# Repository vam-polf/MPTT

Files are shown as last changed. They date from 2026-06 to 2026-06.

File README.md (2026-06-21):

# MPTT — Mini Push To Talk

> LoRa 对讲机 v0.1 | STM32WLE5 + WM8960 | 2层 FR-4 35×55mm

基于 E77-400M22S (STM32WLE5) 和 WM8960 音频 Codec 的 LoRa 手持对讲机。单节锂电池供电，USB-C 充电，SMA 外接天线。

## 目录结构

```
mptt/
├── README.md                 本文件
├── docs/                     设计文档 (见 docs/README.md)
├── hardware/                 硬件设计 (原理图、BOM、PCB、EasyEDA 工程)
├── reference/datasheets/     芯片数据手册
└── firmware/                 固件
    ├── build.bat             构建主固件 (Windows)
    ├── Makefile              构建 / 烧录快捷入口
    ├── link.ld               链接脚本
    ├── startup.c             启动代码
    ├── include/              头文件
    │   ├── stm32wle5xx.h     MCU 寄存器定义
    │   └── audio_wm8960.h    音频驱动 API
    ├── src/                  源代码
    │   ├── main.c            应用层 (PTT 状态机 + DSP 后处理)
    │   └── audio_wm8960.c    音频底层 (MCLK/I2C/I2S/WM8960, 已冻结)
    ├── tools/                调试 / 验证脚本 (pyocd)
    │   ├── selftest.py       自动验证 (模拟 PTT, 无需人工)
    │   ├── readproc.py       读取处理后缓冲 → WAV
    │   ├── readdiag.py       读取 DIAG 诊断区
    │   └── ...
    └── build/                构建产物 (gitignore)
        ├── fw.elf
        └── fw.bin
```

## 固件快速开始

```bat
cd firmware
build.bat
pyocd flash -t stm32wle5cbux build\fw.bin
python tools\selftest.py
```

音频底层配置与调试知识库见 `D:\kb\wm8960\mptt-从零调试实战手册.md`。

## 核心器件

| 位号 | 型号 | 功能 |
|---|---|---|
| U1 | E77-400M22S | STM32WLE5 LoRa 模组, 400-470MHz |
| U2 | WM8960CGEFL/RV | 音频 Codec + 1W D类功放 |
| U3 | ME6211C33M5G-N | 3.3V 500mA LDO |
| U4 | TP4056-42-ESOP8 | 锂电池充电管理 |
| U5 | DW01A + U6 8205A | 电池保护 + MOSFET 开关 |

## 设计工具

- **EDA**: 立创EDA专业版
- **PCB**: JLCPCB 2层 FR-4, 35×55mm

## 许可证

MIT License

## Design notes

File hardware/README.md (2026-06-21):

# 硬件文档索引

| 文件 | 内容 |
|---|---|
| [SCHEMATIC.md](SCHEMATIC.md) | 原理图模块说明、关键引脚 |
| [NETLIST.md](NETLIST.md) | 40 网络连接表（含 I2S 半双工） |
| [BOM.md](BOM.md) | 物料清单 53 项 |
| [PCB.md](PCB.md) | PCB 布局与生产 |
| `lora_waikie_2026-06-05.epro2` | EasyEDA Pro 工程源文件 |
| `mptt_schematic_v0.1.pdf` | 原理图 PDF 导出 |

引脚与固件对应关系以 **SCHEMATIC.md + NETLIST.md** 为准（2026-06-21 已与 bringup 固件交叉核对）。

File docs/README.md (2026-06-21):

# 文档索引

| 文档 | 内容 |
|---|---|
| [DESIGN_v0.1.md](DESIGN_v0.1.md) | v0.1 **硬件**系统设计（架构、电源、WM8960、BOM、PCB 指南） |

固件架构与音频调试（WM8960 寄存器、I2S 时钟、PTT 录放）见知识库：

- `D:\kb\wm8960\mptt-从零调试实战手册.md`（最终实测配置，权威）
- 代码：`firmware/src/main.c`（应用）、`firmware/src/audio_wm8960.c`（音频驱动）

硬件接线速查见 `hardware/SCHEMATIC.md`、`hardware/NETLIST.md`。

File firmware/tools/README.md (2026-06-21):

# pyocd 调试 / 验证工具

在 `firmware/` 目录下运行:

```bat
python tools\selftest.py      # 自动模拟 PTT, 客观验证通路
python tools\readdiag.py        # 读 DIAG 诊断区 (不复位)
python tools\readproc.py        # 导出处理后音频 → tools\output\proc.wav
python tools\noiseanalyze.py    # 频谱分析
python tools\read_wm.py         # 读 WM8960 shadow (I2C 探测)
python tools\probe.py           # GPIO / 外设快照
```

生成的 WAV 文件写入 `tools/output/` (已 gitignore)。

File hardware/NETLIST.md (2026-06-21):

# 网络连接表 v0.1

> 40 个网络 | 作者: vam-polf | 2026-06-07

## 电源域

| 网络 | 电压 | 来源 | 用途 |
|---|---|---|---|
| USB_5V | 5V | USB-C (J1) | 充电输入 |
| BAT+ | 3.7-4.2V | 锂电池正极 | 电池供电 |
| DWBAT+ | 3.7-4.2V | DW01A 输出 | 保护后的电池电压 |
| BAT- | GND | 电池负极 | 电池回路 |
| +3.3V | 3.3V | ME6211 LDO 输出 | 主供电 |
| +3.3V_E77 | 3.3V | 经0Ω跳线 | E77 模块专用供电 |
| +3.3V_DVDD | 3.3V | WM8960 数字供电 | 音频数字部分 |
| +3.3V_BVDD | 3.3V | WM8960 缓冲供电 | 音频缓冲 |
| +3.3V_AVDD | 3.3V | WM8960 模拟供电 | 音频模拟部分 |
| +1.65V | 1.65V | WM8960 内部 VREF | 中点参考电压 |
| VBAT_SPK | 3.7-4.2V | 电池直供 SPKVDD | 扬声器功放供电 |

## 电源管理

| 网络 | 功能 |
|---|---|
| PROG | TP4056 充电电流设置 (R17/R18分压 ≈5.1kΩ→~200mA) |
| CHRG | TP4056 充电状态指示 (LED U8) |
| STDBY | TP4056 充满指示 (LED U9) |
| OC | DW01A 过充检测 |
| OD | DW01A 过放检测 |
| VM | DW01A 过流检测 |

## USB-C

| 网络 | 功能 |
|---|---|
| CC1 | USB-C CC1 配置通道 (5.1kΩ下拉) |
| CC2 | USB-C CC2 配置通道 (5.1kΩ下拉) |

## 射频

| 网络 | 功能 |
|---|---|
| ANT | SMA 天线连接 (J2), 50Ω 匹配 |

## 数字音频 (I2S)

| 网络 | MCU 引脚 | 方向 | 功能 |
|---|---|---|---|
| I2S_MCLK | PA3 (TIM2_CH4) | E77→WM8960 pin11 | 主时钟 2.286MHz (PWM, 非 I2S2_MCK) |
| I2S_BCLK | PA8 (I2S2_CK) | 录: WM8960→E77 / 放: E77→WM8960 pin12 | 位时钟 |
| I2S_LRCLK | PA9 (I2S2_WS) | 同上 pin13 (DACLRC) | 帧时钟 |
| I2S_SD | PA10 (I2S2_SD) | **半双工共线** pin14+16 | 录音 ADCDAT→MCU / 播放 MCU→DACDAT |
| ADCLRC | — (PCB 浮空) | — | WM8960 pin15 未接 MCU；固件 R9 ALRCGPIO=1 |

> 录音时 WM8960 当 I2S 主、STM32 当从；播放时相反。详见 `firmware/src/audio_wm8960.c`。

## 控制总线 (I2C)

| 网络 | 功能 |
|---|---|
| I2C_SCL | WM8960 配置时钟 |
| I2C_SDA | WM8960 配置数据 |

## 模拟音频

| 网络 | 功能 |
|---|---|
| MIC+ | 驻极体麦克风 正极输入 |
| MICBIAS | WM8960 麦克风偏置电压 |
| LINPUT1 | 线路输入 1 / 麦克风输入 |
| SPK_LP | 扬声器 左声道 正极 |
| SPK_LN | 扬声器 左声道 负极 |

## 控制/调试

| 网络 | 功能 |
|---|---|
| NRST | 系统复位 |
| SWDIO | SWD 调试数据 |
| SWCLK | SWD 调试时钟 |
| PTT | 对讲按键 (Push-To-Talk) |
| BAT_ADC | 电池电压 ADC 采样 |

## 内部网络

| 网络 | 说明 |
|---|---|
| $1N287 | 内部网络 (自动生成) |
| $1N290 | 内部网络 (自动生成) |
| GND | 公共地 |

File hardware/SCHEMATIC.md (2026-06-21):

# 原理图设计说明 v0.1

> EasyEDA Pro | 单页原理图 P1 | 53 个元件 | 作者: vam-polf | 2026-06-07

## 功能模块划分

### 1. 核心控制 — E77-400M22S (U1)

STM32WLE5 内置 LoRa 射频的单片机模组。负责:
- LoRa 无线收发 (400MHz)
- I2S 音频数据流控制
- I2C 配置 WM8960
- GPIO 控制 PTT/充电状态
- ADC 电池电压采样

关键引脚连接:
- PA3(TIM2_CH4 MCLK)/PA8(I2S2_CK)/PA9(I2S2_WS)/PA10(I2S2_SD) → I2S 到 WM8960
- PB6/PB7 → I2C 到 WM8960
- PB8 → PTT 按键（上拉，按下=低；固件见 `firmware/src/main.c`）
- PA0 → BAT_ADC
- PA13/PA14 → SWD (J4)

### 2. 音频编解码 — WM8960 (U2)

立体声音频 Codec + 1W D类功放。

模拟部分:
- MIC+/LINPUT1 → 麦克风输入
- SPK_LP/SPK_LN → 扬声器输出 (BTL 桥接)
- MICBIAS → 驻极体偏置

数字部分:
- I2S: MCLK(PA3) / BCLK(PA8) / LRCLK(PA9) / SD(PA10 半双工)
- ADCLRC (WM8960 pin15): **PCB 浮空**，固件设 ALRCGPIO=1
- I2C 配置接口 (PB6/PB7 → SCL/SDA)

电源分组:
- +3.3V_DVDD: 数字核心
- +3.3V_BVDD: 缓冲器
- +3.3V_AVDD: 模拟电路
- VBAT_SPK: 功放级 (直连电池)

### 3. 电源管理

```
USB-C 5V → TP4056 → DW01A → 8205A → BAT+
                         ↓
                    ME6211 → +3.3V → 各路供电
```

- **TP4056 (U4)**: 恒流/恒压充电, 200mA 充电电流, LED 状态指示
- **DW01A (U5)**: 过充(4.25V)/过放(2.5V)/过流保护
- **8205A (U6)**: 双 MOSFET 开关, 切断电池回路
- **ME6211 (U3)**: 3.3V 500mA LDO, 输入6V, 低压差

### 4. USB-C 接口 (J1)

- VBUS → USB_5V (充电输入)
- D+/D- → E77 USB (预留, 当前未连)
- CC1/CC2 → 各接 5.1kΩ 下拉 (R17/R18)

### 5. 天线接口 (J2)

SMA 母座, 50Ω 特性阻抗。PCB 走线需控制阻抗。

### 6. 外设接口

| 连接器 | 用途 |
|---|---|
| J3 (1.25mm 2P) | 锂电池连接 |
| J4 (2.54mm 2×3P) | SWD 调试 (SWDIO/SWCLK/NRST/GND) |
| J5 (ZH 1.5mm 2P) | 扬声器 8Ω/1W |
| J6 (ZH 1.5mm 2P) | 驻极体麦克风 |

## 设计规则

- 原理图坐标单位: 0.01inch (10 mil)
- 元件总数: 53
- 网络总数: 40
- DRC 状态: 通过

## 去耦电容布局

每个 IC 电源引脚就近放置 100nF + 10μF/22μF 去耦电容:
- E77: C9/C10/C11/C12/C13/C14/C15/C16/C17 + 电源隔离 (R7/R8/R9/R10/R11 0Ω 跳线)
- WM8960: C1/C2/C3/C4/C5 + 各电源域独立去耦
- ME6211: 输入 C18 (1μF), 输出大电容组
- TP4056: 输入/输出电容

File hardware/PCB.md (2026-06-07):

# PCB 设计说明 v0.1

> 2层 FR-4 | 35×55mm | 作者: vam-polf | 2026-06-07

## 物理参数

| 参数 | 值 |
|---|-----|
| 层数 | 2 层 (Top/Bottom) |
| 板厚 | 1.6 mm |
| 铜厚 | 1 oz |
| 基材 | FR-4 |
| 最小线宽 | 6 mil |
| 最小间距 | 6 mil |
| 最小过孔 | 0.3mm 钻孔 / 0.6mm 外径 |
| 阻焊颜色 | 绿色 |
| 字符颜色 | 白色 |
| 焊盘喷镀 | 有铅喷锡 |
| 过孔处理 | 过孔盖油 |

## 布局策略

### 区域划分

```
┌─────────────────────────────────────┐
│  ANT (J2)    E77 (U1)     TP4056    │
│   SMA         LoRa         U4       │
│                                      │
│                       DW01A + 8205A │
│  WM8960 (U2)        U5    +  U6     │
│    Audio                            │
│                                      │
│  J1 USB-C   ME6211    SWD   Batt    │
│             (U3)      (J4)  (J3)    │
└─────────────────────────────────────┘
```

### 布局原则

1. **RF 优先**: 天线区域远离数字噪声源, SMA 座靠近 E77, 50Ω 走线尽量短
2. **电源分区**: 充电/保护电路远离音频模拟区域
3. **去耦就近**: 每个 IC 电源引脚 2mm 内放置去耦电容
4. **GND 完整性**: 底面大面积 GND 铜皮, 顶面保留 GND 回路

### 关键走线

| 走线 | 宽度 | 层 | 说明 |
|---|---|-----|---|
| ANT (RF) | 计算阻抗 | Top | 50Ω 微带线 |
| BAT+ / USB_5V | 30-40 mil | Top | 大电流电源 |
| VBAT_SPK | 30 mil | Top | 功放供电 |
| 信号线 | 12 mil | Top/Bottom | 通用信号 |
| GND | 铺铜 | Bottom | 完整地平面 |

## 元件面分配

全部元件置于 **Top Layer**:
- 52 个 SMD 元件 (Top)
- 1 个直插元件 J4 (2.54mm 2×3P SWD)
- 0 个元件在 Bottom

## 生产文件

通过 EasyEDA Pro → 文件 → 导出 → 嘉立创PCB下单 直接生成 Gerber。
或在 EDA 中导出:
- Gerber (RS-274X)
- NC Drill
- BOM (CSV)
- CPL 坐标文件 (CSV)

## SMT 贴片

- 只贴顶层
- JLCPCB 标准型 SMT
- E77 和 WM8960 需邮寄物料 (嘉立创无现货)

## 已知限制

- WM8960 已停产，需从淘宝/库存采购
- RF 天线走线未做严格阻抗仿真 (第一版原型)
- 无屏蔽罩，RF 可能干扰音频电路

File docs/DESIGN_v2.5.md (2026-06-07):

# MPTT v2.5 硬件设计文档

> LoRa 对讲机 | E77-400M22S (STM32WLE5) + WM8960 | 2层 FR-4 35×55mm
> 设计日期: 2026-06-07 | EDA: 立创EDA专业版 V3.2.121

---

## 目录

1. [系统概述](#1-系统概述)
2. [架构框图](#2-架构框图)
3. [核心模组: E77-400M22S](#3-核心模组-e77-400m22s)
4. [音频子系统: WM8960](#4-音频子系统-wm8960)
5. [电源管理](#5-电源管理)
6. [接口与外设](#6-接口与外设)
7. [电源树与去耦策略](#7-电源树与去耦策略)
8. [物料清单 (BOM)](#8-物料清单-bom)
9. [PCB 设计指南](#9-pcb-设计指南)
10. [设计决策与取舍](#10-设计决策与取舍)

---

## 1. 系统概述

MPTT v2.5 是一款基于 STM32WLE5 的 LoRa 手持对讲机。单节锂电池供电，USB-C 充电，SMA 外接天线。

### 1.1 核心能力

| 功能 | 实现 |
|---|---|
| 无线通信 | E77-400M22S LoRa 扩频模块, 400-470MHz |
| 音频采集 | 驻极体麦克风 → WM8960 ADC → I2S → MCU |
| 音频播放 | MCU → I2S → WM8960 DAC → 1W D类功放 → 扬声器 |
| 电源 | 单节锂电池, TP4056 充电, DW01A 保护, ME6211 LDO |
| 调试 | SWD 2×3P 接口 |
| 充电 | USB-C (5V/200mA) |

### 1.2 设计选型理由

选用**模组方案**（E77-400M22S）而非裸芯片，原因：
- 避免 RF 阻抗匹配和天线设计的复杂性
- 模组已过 FCC/CE 认证
- 内置 STM32WLE5 + RF 前端，缩小 PCB 面积
- 简单、稳定、可靠

选用**WM8960 模拟 Codec** 而非数字 MEMS 麦克风方案，原因：
- 驻极体麦克风成本极低（~1元），数字 MEMS 需 5-10 元
- WM8960 内置 1W D 类功放，无需额外功放 IC
- 立体声能力为未来扩展预留

---

## 2. 架构框图

```
                        ┌──────────────────────────────────────┐
   SMA Antenna ────────►│                                      │
                        │         E77-400M22S (U1)              │
                        │     STM32WLE5 + SX1262 RF Frontend    │
                        │                                      │
                        │  ┌─────────────────────────────────┐ │
   PTT Button (SW1) ───┼──► PB0 (GPIO)                       │ │
                        │  │                                  │ │
   Battery ADC ────────┼──► PA0 (ADC)                        │ │
                        │  │                                  │ │
   SWD (J4) ───────────┼──► PA13(SWDIO) / PA14(SWCLK)        │ │
                        │  │                                  │ │
                        │  │   I2S ┌──────────────────────┐   │ │
                        │  │  ───►│    WM8960 (U2)        │   │ │
                        │  │  ◄───│  Audio Codec + Amp    │   │ │
                        │  │      │                       │   │ │
                        │  │  I2C │  MIC+ ◄── J6 (Mic)   │   │ │
                        │  │  ───►│  SPK  ──► J5 (Spkr)  │   │ │
                        │  │      └──────────────────────┘   │ │
                        │  └─────────────────────────────────┘ │
                        │                                      │
                        │   Power ┌────────────────────────┐   │
   USB-C (J1) ─────────┼────────►│ TP4056 → BAT → DW01A   │   │
                        │         │   ↓          ↓         │   │
   Battery (J3) ───────┼────────►│ ME6211 → +3.3V         │   │
                        │         └────────────────────────┘   │
                        └──────────────────────────────────────┘
```

---

## 3. 核心模组: E77-400M22S

### 3.1 模组规格

| 参数 | 值 |
|---|-----|
| 型号 | E77-400M22S |
| MCU | STM32WLE5CBU6 (ARM Cortex-M4 48MHz) |
| RF 芯片 | SX1262 |
| 频段 | 400-470 MHz |
| 发射功率 | 最大 +22 dBm |
| 接收灵敏度 | -138 dBm @ SF12 BW=125kHz |
| Flash/RAM | 128KB / 48KB |
| 供电 | 1.8-3.6V |
| 尺寸 | 14×20 mm (邮票孔封装) |
| LCSC | C2777170 |

### 3.2 引脚分配

#### I2S 音频接口

| E77 引脚 | STM32 功能 | 连接目标 | 说明 |
|---|---|---|---|
| 8 | PA4 (I2S1_WS) | WM8960 ADCLRC | ADC 字时钟 |
| 9 | PA5 (I2S1_CK) | WM8960 I2S_BCLK | I2S 位时钟 |
| 10 | PA6 (I2S1_SD) | WM8960 I2S_SD | I2S 数据输出 (MCU→Codec) |
| 11 | PA7 (I2S1_MCK) | WM8960 I2S_MCLK | 主时钟 |

#### I2C 控制接口

| E77 引脚 | 功能 | 连接目标 |
|---|---|---|
| 14 | PB6 (I2C1_SCL) | WM8960 SCL |
| 15 | PB7 (I2C1_SDA) | WM8960 SDA |

#### 控制与状态

| E77 引脚 | 功能 | 连接目标 | 说明 |
|---|---|---|---|
| 1 | NRST | J4 (SWD) + R19上拉 | 系统复位, 100kΩ 上拉到 +3.3V |
| 18 | PB0 | SW1 (PTT) + R12下拉 | 对讲按键, 4.7kΩ 下拉 |
| 16 | PA0 (ADC) | BAT_ADC (R20分压) | 电池电压检测, 100kΩ分压 |

#### SWD 调试

| E77 引脚 | 功能 | J4 引脚 |
|---|---|---|
| 2 | PA13 (SWDIO) | J4-3 |
| 3 | PA14 (SWCLK) | J4-4 |
| 1 | NRST | J4-5 |

### 3.3 E77 电源与去耦

- VCC 由 `+3.3V_E77` 供电（通过 0Ω 跳线 R7/R8/R9/R10/R11 与主 3.3V 隔离）
- 多组去耦电容: C9(100nF), C10(100nF), C11(10μF), C12(100nF), C13(100nF), C14(22μF), C15(100nF), C16(10μF), C17(10μF)
- 0Ω 跳线允许独立测量 E77 功耗

---

## 4. 音频子系统: WM8960

### 4.1 Codec 规格

| 参数 | 值 |
|---|-----|
| 型号 | WM8960CGEFL/RV |
| 封装 | QFN-32 (5×5mm) |
| DAC SNR | 98dB |
| ADC SNR | 94dB |
| 功放输出 | 1W @ 8Ω (D类, BTL) |
| 耳机输出 | 40mW @ 16Ω |
| 麦克风 | 差分/单端, 内置 PGA + ALC |
| 接口 | I2S (标准/左对齐/DSP), I2C 控制 |
| 状态 | ⚠️ 已停产, 需淘宝/库存采购 |

### 4.2 信号链

```
TX路径 (发送):
  Electret Mic → MIC+/LINPUT1 → WM8960 PGA → ADC → I2S_SD → E77 → LoRa TX

RX路径 (接收):
  LoRa RX → E77 → I2S_SD → WM8960 DAC → D类功放 → SPK_LP/SPK_LN → Speaker (J5)
```

### 4.3 WM8960 引脚连接

#### I2S 数字音频

| WM8960 引脚 | 信号 | 连接 |
|---|---|---|
| 13 | ADCLRC | E77 PA4 (I2S1_WS) |
| 14 | DACLRC | E77 PA7 (I2S1_MCK) — 复用为 LRC |
| 15 | BCLK | E77 PA5 (I2S1_CK) |
| 16 | ADCDAT | E77 PA6 (I2S1_SD) |
| 17 | DACDAT | E77 PA7 — 双向数据 |

#### I2C 控制

| WM8960 引脚 | 连接 |
|---|---|
| 19 (SCLK) | E77 PB6 (I2C1_SCL) |
| 20 (SDIN) | E77 PB7 (I2C1_SDA) |

I2C 地址: 0x1A (7-bit, CSB=GND)

#### 模拟音频

| WM8960 引脚 | 功能 | 外部连接 |
|---|---|---|
| 8 (LINPUT1) | 麦克风输入 | 驻极体 MIC+ (J6), 隔直电容 |
| 9 (MICBIAS) | 麦克风偏置 | 通过电阻供电给驻极体 |
| 25 (SPK_LP) | 扬声器 正 | J5-1 (ZH1.5 2P) |
| 26 (SPK_LN) | 扬声器 负 | J5-2 |

SPK_LP/SPK_LN 为 BTL 桥接输出，无需隔直电容。

#### 电源分组

WM8960 有多组独立电源域，需分别去耦：

| 电源引脚 | 网络 | 去耦 |
|---|---|---|
| 1, 2, 31 (AVDD) | +3.3V_AVDD | C1(22μF) + C2(100nF) + C3(100nF) |
| 10, 18 (DVDD) | +3.3V_DVDD | C5(10μF) + C6(100nF) |
| 22 (SPKVDD1) | VBAT_SPK | 电池直供, C7(22μF) + C8(100nF) |
| 28 (SPKVDD2) | VBAT_SPK | 同上 |
| 12 (DBVDD) | +3.3V_BVDD | 缓冲供电 |

**设计要点**: SPKVDD 直接接电池电压 (3.7-4.2V)，不经过 3.3V LDO。D 类功放在较高电压下效率更好。

### 4.4 麦克风电路

- 驻极体麦克风 (6027 单指向, -42dB, 6×2.7mm)
- MICBIAS 提供偏置电压 (~2.0V via WM8960 内部)
- 隔直电容 (C4) 耦合到 LINPUT1
- 差分输入可抑制共模噪声

---

## 5. 电源管理

### 5.1 电源架构

```
USB-C 5V (J1)
   │
   ▼
┌──────────┐    ┌──────────┐    ┌──────────┐
│  TP4056  │───►│  DW01A   │───►│  8205A   │──► BAT+ (J3)
│  Charger │    │ Protect  │    │ MOSFET   │
│  U4      │    │  U5      │    │  U6      │
└────┬─────┘    └──────────┘    └──────────┘
     │
     ├── CHRG ──► U8 (Red LED)  充电指示
     └── STDBY ─► U9 (Green LED) 充满指示

BAT+ ──► ME6211 (U3) ──► +3.3V ──┬── +3.3V_E77 (经0Ω跳线)
                                  ├── +3.3V_AVDD
                                  ├── +3.3V_DVDD
                                  └── +3.3V_BVDD

BAT+ ──► VBAT_SPK (WM8960 功放直供)
```

### 5.2 TP4056 充电管理 (U4)

| 参数 | 值 | 设置方式 |
|---|-----|---|
| 充电电流 | ~200mA | R17//R18 → 5.1kΩ → PROG 引脚 |
| 终止电流 | C/10 (~20mA) | 内部固定 |
| 充电电压 | 4.2V ±1% | 内部固定 |
| 输入电压 | 4.5-6V (USB-C 5V) | |
| 温度保护 | 禁用 | TEMP 引脚接 GND |

充电状态指示:
- CHRG (开漏): 充电中 → LED U8 (红) 亮
- STDBY (开漏): 充满 → LED U9 (绿) 亮
- 两个 LED 均通过限流电阻 (R16: U8, R14: U9) 连接到 +3.3V

**充电电流计算**: I_CHG = 1000V / R_PROG
- R17 = 5.1kΩ, R18 = 5.1kΩ 并联 → R_PROG ≈ 2.55kΩ
- I_CHG ≈ 392mA (理论值)
- 实际限流约 200mA (考虑 USB 供电能力)

### 5.3 DW01A 电池保护 (U5) + 8205A MOSFET (U6)

DW01A 监控电池状态，通过 8205A 双 MOSFET 切断充放电回路：

| 保护功能 | 阈值 | 动作 |
|---|---|---|
| 过充保护 | 4.25V ±50mV | OC→高, 切断充电 MOSFET |
| 过放保护 | 2.40V ±100mV | OD→高, 切断放电 MOSFET |
| 放电过流 | 150mV (≈3A) | OD→高 |
| 短路保护 | 1.5V | 立即切断 |

8205A: 双 N 沟道 MOSFET, Vds=20V, Id=6A, Rds(on)=25mΩ

### 5.4 ME6211 LDO (U3)

| 参数 | 值 |
|---|-----|
| 型号 | ME6211C33M5G-N |
| 封装 | SOT-23-5 |
| 输入电压 | 最大 6V |
| 输出电压 | 3.3V 固定 |
| 输出电流 | 最大 500mA |
| 压差 | 100mV @ 200mA |
| LCSC | C82942 |

输入电容 C18 (1μF), 输出电容由各路去耦组成。

### 5.5 功耗估算

| 工作模式 | E77 | WM8960 | 其他 | 总计 |
|---|-----|---|---|---|
| RX 监听 | ~8mA | ~2mA | ~1mA | ~11mA |
| TX (22dBm) | ~120mA | ~10mA | ~1mA | ~131mA |
| 待机 | ~2μA | 0 (掉电) | ~5μA | ~7μA |

500mAh 电池续航: RX ~45小时, TX ~3.5小时

---

## 6. 接口与外设

### 6.1 USB-C (J1)

| 引脚 | 连接 | 说明 |
|---|---|---|
| VBUS | USB_5V | 充电输入 |
| D+/D- | NC | 数据线未使用 (E77 USB 预留) |
| CC1 | 5.1kΩ 下拉 (R17) | 配置为 UFP (受电设备) |
| CC2 | 5.1kΩ 下拉 (R18) | 同上 |
| GND | GND | |

Type-C 母座, 卧贴封装。CC1/CC2 各接 5.1kΩ 到 GND → USB-C 主机识别为需要 5V 供电的设备。

### 6.2 SMA 天线 (J2)

- 型号: SMA-KE-5 (母座, 正脚)
- 50Ω 特性阻抗
- 走线尽量短, 参考地层完整
- 无额外匹配网络 (E77 模组内部已匹配)

### 6.3 SWD 调试接口 (J4)

2×3P, 2.54mm 间距, 直插方针:

| 引脚 | 信号 |
|---|---|
| 1 | +3.3V |
| 2 | SWDIO |
| 3 | GND |
| 4 | SWCLK |
| 5 | GND |
| 6 | NRST |

### 6.4 电池连接器 (J3)

1×2P, 1.25mm PicoBlade 卧贴:
- Pin 1: BAT+ (正极)
- Pin 2: GND (负极)

### 6.5 扬声器 (J5)

ZH 1.5mm 1×2P 立贴:
- Pin 1: SPK_LP (WM8960 输出正)
- Pin 2: SPK_LN (WM8960 输出负)

推荐扬声器: 8Ω/1W, 直径 20mm 腔体

### 6.6 麦克风 (J6)

ZH 1.5mm 1×2P 立贴:
- Pin 1: MIC+ (经隔直电容到 WM8960 LINPUT1)
- Pin 2: GND

推荐麦克风: 6027 单指向驻极体, -42dB

### 6.7 PTT 按键 (SW1)

- 型号: TS-1187A-B-A-B (5.1×5.1×1.5mm 立贴)
- 连接: PB0 → SW1 → GND
- 内部上拉: E77 PB0 内置弱上拉
- 外部下拉: R12 (4.7kΩ) 确保默认低电平

### 6.8 电池电压检测

- PA0 (ADC) ← R19 (100kΩ) ← BAT+ ← R20 (100kΩ) → GND
- 分压比: 1/2
- 满电 4.2V → ADC 读 2.1V

---

## 7. 电源树与去耦策略

### 7.1 全局去耦布局

```
+3.3V ──┬── C18(1μF)   ← ME6211 输出
        ├── C5(10μF)    ← WM8960 DVDD
        ├── C1(22μF)    ← WM8960 AVDD
        ├── C2,C3,C6,C8,C9,C10,C12,C13,C15 (100nF×9)
        └── C11,C16,C17 (10μF×3)

VBAT_SPK ──┬── C7(22μF)
           └── C14(22μF)  ← WM8960 SPKVDD

+3.3V_E77 ── C11,C14,C16,C17  ← 经0Ω隔离后

BAT+ ── C4(22μF)  ← TP4056 输入
```

### 7.2 电源域隔离

| 隔离方式 | 网络 | 目的 |
|---|---|---|
| 0Ω 跳线 | +3.3V → +3.3V_E77 | 可断开独立测量 E77 电流 |
| 独立 LDO | +3.3V_AVDD | 模数隔离 (暂用同一 LDO) |
| 直连电池 | VBAT_SPK | D类功放高压高效 |

---

## 8. 物料清单 (BOM)

### 核心 IC/模组 (9项)

| 位号 | 型号 | 封装 | 功能 | LCSC |
|---|---|---|---|---|
| U1 | E77-400M22S | 邮票孔模块 | STM32WLE5 LoRa | C2777170 |
| U2 | WM8960CGEFL/RV | QFN-32 | 音频 Codec | ⚠️ 停产 |
| U3 | ME6211C33M5G-N | SOT-23-5 | 3.3V LDO | C82942 |
| U4 | TP4056-42-ESOP8 | ESOP-8 | 锂电池充电 | C382139 |
| U5 | DW01A | SOT-23-6 | 电池保护 | C351377 |
| U6 | 8205A | TSSOP-8 | 双 MOSFET | C440346 |
| U8 | XL-1608SURC-06 | 0603 | 红色LED (充电) | C965802 |
| U9 | GL0603UG01 | 0603 | 绿色LED (充满) | C52372 |
| SW1 | TS-1187A-B-A-B | 5.1×5.1mm | PTT 按键 | |

### 连接器 (7项)

| 位号 | 型号 | 类型 |
|---|---|---|
| J1 | TYPE-C-31-M-12 | USB-C 母座 卧贴 |
| J2 | SMA-KE-5 | SMA 母座 |
| J3 | 1.25T-2P卧贴 | PicoBlade 1.25mm 2P |
| J4 | 1271WV-2x3P | 2.54mm 2×3P 直插 |
| J5 | ZH1.5-2P-LT | ZH 1.5mm 2P 立贴 |
| J6 | ZH1.5-2P-LT | ZH 1.5mm 2P 立贴 |

### 电阻 (20项, 0603)

| 位号 | 阻值 | 用途 |
|---|---|---|
| R1 | 10kΩ | 通用上拉 |
| R2,R3,R5 | 1kΩ | LED 限流 / 通用 |
| R4 | 100Ω | 去耦隔离 |
| R6,R14,R16 | 10kΩ | 上拉/限流 |
| R7,R8,R9,R10,R11 | 0Ω | 电源跳线 (E77 隔离) |
| R12,R13 | 4.7kΩ | 下拉/CC 配置 |
| R15 | 2.2kΩ | 偏置 |
| R17,R18 | 5.1kΩ | PROG 充电电流设置 / CC 下拉 |
| R19,R20 | 100kΩ | BAT_ADC 分压 |

### 电容 (18项)

| 位号 | 容值 | 封装 | 用途 |
|---|---|---|---|
| C1,C4,C7,C14 | 22μF/10V | 0805 | WM8960 AVDD/SPKVDD 去耦 |
| C5,C11,C16,C17 | 10μF/10V | 0805 | 电源去耦 |
| C2,C3,C6,C8,C9,C10,C12,C13,C15 | 100nF/50V | 0603 | 高频去耦 |
| C18 | 1μF/50V | 0603 | LDO 输入 |

---

## 9. PCB 设计指南

### 9.1 物理规格

| 参数 | 值 |
|---|-----|
| 层数 | 2 层 |
| 板厚 | 1.6mm |
| 铜厚 | 1oz |
| 基材 | FR-4 |
| 尺寸 | 35×55mm |
| 最小线宽/间距 | 6mil |
| 过孔 | 0.3mm 钻孔 / 0.6mm 外径 |
| 阻焊 | 绿色 |
| 表面处理 | 有铅喷锡 |

### 9.2 布局分区

```
┌──────────────────────────────────────┐
│  ANT (J2)         E77 (U1)           │  ← RF 区域
│  [SMA 左上角]    [LoRa 模组 上方]     │
│                                      │
│              WM8960 (U2)             │  ← 音频区域
│              [Codec 中部偏右]         │
│                                      │
│  J1(USB-C)  U4(TP4056)  U5+U6(DW01) │  ← 电源区域
│  [左下角]   [中下部]     [右侧]       │
│                                      │
│  J4(SWD)    U3(ME6211)    J3(BAT)   │  ← 接口区域
│  [底部]     [中下部]       [底部]     │
└──────────────────────────────────────┘
```

### 9.3 关键走线规则

| 信号 | 线宽 | 间距 | 层 | 说明 |
|---|---|---|-----|---|
| RF ANT | 计算 50Ω | ≥20mil 到 GND | Top | 微带线, 尽量短 |
| VBAT_SPK | 30mil | — | Top | 功放大电流 |
| BAT+ | 30mil | — | Top | 主供电 |
| USB_5V | 30mil | — | Top | 充电输入 |
| I2S 信号 | 12mil | ≥12mil | Top | 等长 (±5mil) |
| I2C | 12mil | — | Top/Bottom | 非高速 |
| GND | 铺铜 | — | Bottom | 完整地平面 |

### 9.4 注意事项

1. **RF 隔离**: 天线区域远离数字/电源噪声源，地平面完整无割裂
2. **音频隔离**: WM8960 模拟区域 (AVDD/SPKVDD) 与数字区域之间用 0Ω 跳线隔离地回路
3. **SWD 防护**: NRST 线上拉 100kΩ，SWDIO/SWCLK 串 100Ω 保护
4. **散热**: TP4056 在 200mA 充电时功耗约 0.3W，无需额外散热
5. **去耦就近**: 每个 IC 电源引脚 2mm 内放置 100nF 电容

---

## 10. 设计决策与取舍

### 10.1 模组 vs 裸芯片

| 方案 | 优点 | 缺点 |
|---|---|---|
| E77 模组 (✅ 选用) | 免 RF 匹配/认证, 邮票孔易焊接, 尺寸小 | 成本较高 (~30元), 引脚固定 |
| 裸 STM32WLE5 + RF | 灵活, 成本低 | RF 设计复杂, 需阻抗匹配, 需认证 |

### 10.2 WM8960 模拟 Codec vs 数字 MEMS 方案

| 方案 | 优点 | 缺点 |
|---|---|---|
| WM8960 (✅ 选用) | 内置功放, 麦克风便宜, 立体声 | 芯片停产, QFN 焊接难度 |
| INMP441 + MAX98357A | 全数字, 噪声低, 芯片在产 | 成本高 (~15元), 需要独立功放, 更多 PCB 面积 |

### 10.3 USB-C 充电 vs 专用充电口

选用 USB-C 母座 (UFP 模式)，兼容主流充电器和数据线。CC1/CC2 各 5.1kΩ 下拉 → 标准 5V 供电。

### 10.4 已知限制

1. **WM8960 停产**: 需淘宝/库存采购，长期维护需考虑替换方案
2. **无屏蔽罩**: RF 可能干扰音频电路，需实测评估
3. **RF 天线未做阻抗仿真**: 第一版原型基于模组厂家参考设计
4. **2 层 PCB**: 无专门的地平面层，需底层大面积铺铜
5. **无 ESD 保护**: USB/SMA/各连接器未加 TVS，后续版本可增加

---

> **文档版本**: v1.0 | **作者**: ShiTingShui | **日期**: 2026-06-07

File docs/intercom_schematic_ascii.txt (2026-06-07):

================================================================================
                    实时对讲机原理图 (ASCII)
================================================================================

                              3.3V
                                │
      ┌─────────────────────────┼─────────────────────────┐
      │                         │                         │
      │    ┌──────────────┐     │     ┌──────────────┐    │
      │    │E77-400MBL-01 │     │     │  INMP441     │    │
      │    │   LoRa模块   │     │     │ 数字麦克风    │    │
      │    ├──────────────┤     │     ├──────────────┤    │
      │    │              │     │     │              │    │
      │  1─┼── 3.3V      ─┼─────┼─────┼── VDD        │    │
      │  2─┼── VCC       ─┼─────┼─────┼── 3.3V       │    │
      │  3─┼── REST      │     │     │              │    │
      │  4─┼── SWCLK     │     │     │  2─┬── GND    │    │
      │  5─┼── SWDIO     │     │     │    │    │      │    │
      │  6─┼── GND      ─┼─────┼─────┼────┴──────────│    │
      │  7─┼── PC13      │     │     │              │    │
      │  8─┼── PA15      │     │     │  3─┬── L/R    │    │
      │  9─┼── PB0       │     │     │    │    │      │    │
      │ 10─┼── PB2       │     │     │    └── GND    │    │
      │ 11─┼── PB12(I2S)─┼─────┼─────┼── WS         │    │
      │ 12─┼── PA10(DIN)─┼─────┼─────┼── DATA (IN)  │    │
      │ 13─┼── PA11      │     │     │              │    │
      │ 14─┼── PA12(DAT)─┼─────┼─────┼── DATA (OUT) │    │
      │ 15─┼── PA9(LRCK)─┼─────┼─────┼── LRCK       │    │
      │ 16─┼── PA8(BCLK)─┼─────┼─────┼── BCLK       │    │
      │ 17─┼── GND      ─┼─────┼─────┼── GND        │    │
      │ 18─┼── 3.3V      │     │     │              │    │
      │ 19─┼── TXD       │     │     │  5─┬── SCK    │    │
      │ 20─┼── RXD       │     │     │    │    │      │    │
      │ 21─┼── PB3(SCK)  │     │     │    └── I2S    │    │
      │ 22─┼── PB4       │     │     │              │    │
      │ 23─┼── PB5(IRQ)  │     │     │  6─┬── DATA   │    │
      │ 24─┼── PB6(KEY2) │     │     │    │    │      │    │
      │ 25─┼── PB7(KEY1)─┼─────┼─────┴──────────────│    │
      │ 26─┼── PB8       │     │     │              │    │
      │ 27─┼── PA0       │     │     │              │    │
      │ 28─┼── PA1       │     │     │              │    │
      │ 29─┼── PA4       │     │     │              │    │
      │ 30─┼── PA5       │     │     │              │    │
      │    │              │     │     │              │    │
      │    └──────────────┘     │     └──────────────┘    │
      │                         │                         │
      │    ┌──────────────┐     │     ┌──────────────┐    │
      │    │ MAX98357A    │     │     │   SW-PB      │    │
      │    │  音频功放    │     │     │   按键模块   │    │
      │    ├──────────────┤     │     ├──────────────┤    │
      │    │              │     │     │              │    │
      │  1─┼── VDD       ─┼─────┼─────┼── VCC       ─┼────┼── 3.3V
      │  2─┼── GND       ─┼─────┼─────┼── GND       ─┼────┼── GND
      │  3─┼── DIN       ─┼─────┼─────┤              │     │
      │    │              │     │     │  OUT─┬── KEY  │     │
      │    │              │     │     │      │   │   │     │
      │    │              │     │     │  10K─┴──┬──┘     │
      │    │              │     │     │        │        │
      │  4─┼── BCLK      ─┼─────┼─────┴────────┴────────┘
      │  5─┼── LRCK      ─┼─────┼──────┐
      │  6─┼── GAIN ──┬──┼─────┼──────┤
      │    │         │  │     │      │
      │    └── GND ──┘  │     │      │
      │  7─┼── SD   ──┬──┼─────┼──────┘
      │    │         │  │     │
      │    └── 3.3V ──┘  │     │
      │    └──────────────┘     │
      │                         │
      └─────────────────────────┘

================================================================================
                        连线说明 (NET LIST)
================================================================================

电源网络:
  VCC (3.3V): 
    E77-400MBL-01 Pin1, Pin18
    INMP441 Pin1
    MAX98357A Pin1
    SW-PB Pin1
    C4 (10uF储能电容)

  GND:
    E77-400MBL-01 Pin6, Pin17
    INMP441 Pin2
    MAX98357A Pin2
    SW-PB Pin2
    C4 (10uF)

I2S音频总线:
  I2S_BCLK (位时钟):
    E77 Pin16 (PA8)
    MAX98357A Pin4 (BCLK)
    INMP441 Pin5 (SCK)

  I2S_LRCK (字选择):
    E77 Pin15 (PA9)
    MAX98357A Pin5 (LRCK)
    INMP441 Pin4 (WS)

  I2S_DIN (音频输出到功放):
    E77 Pin10 (PB2)
    MAX98357A Pin3 (DIN)

  I2S_DOUT (麦克风输入):
    E77 Pin14 (PA12)
    INMP441 Pin6 (DATA)

按键控制:
  KEY_PTT (PTT按键):
    E77 Pin25 (PB7)
    R1 (10K上拉)

模块配置:
  INMP441_L/R: GND (左声道地址)
  MAX98357A_GAIN: GND (默认增益)
  MAX98357A_SD: 3.3V (使能)

================================================================================
                        电源滤波电容布置
================================================================================

  C1 (100nF): E77模块电源引脚附近
  C2 (100nF): INMP441电源引脚附近
  C3 (100nF): MAX98357A电源引脚附近
  C4 (10uF):  主电源入口处

================================================================================
                        工作原理说明
================================================================================

1. 发送模式 (按下PTT按键):
   - 麦克风INMP441采集音频
   - 通过I2S接口送入E77模块
   - E77模块将音频数据通过LoRa发送出去

2. 接收模式 (松开PTT按键):
   - E77模块通过LoRa接收音频数据
   - 通过I2S接口发送到MAX98357A功放
   - 功放驱动扬声器发声

================================================================================

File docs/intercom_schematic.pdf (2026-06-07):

# Real-time Intercom Schematic

## E77-400MBL-01 LoRa Module + INMP441 + MAX98357A

## 1. System Architecture

TX Mode (PTT pressed): INMP441 Mic -> I2S -> E77 Module -> LoRa TX
RX Mode (PTT released): E77 Module (LoRa RX) -> I2S -> MAX98357A -> Speaker

## 2. E77 Module Pin Assignment

Function | Pin | Name | Alt Func | Connection
I2S BCLK | 30 | PA5 | SPI1_SCK | INMP441_SCK + MAX98357_BCLK
I2S LRCK | 11 | PB12 | I2S2_WS | INMP441_WS + MAX98357_LRCK
I2S DOUT | 14 | PA12 | TIM1_ETR | INMP441_DATA -> E77
I2S DIN | 12 | PA10 | TIM1_CH3 | E77 -> MAX98357_DIN
PTT Key | 7 | PC13 | WKUP2/GPIO | TX/RX Toggle
Mode Key | 21 | PB3 | RF_IRQ0/GPIO | Mode Select
Func Key | 23 | PB5 | RF_IRQ1/GPIO | Channel Select
Vol+ Key | 26 | PB8 | RF_IRQ2/GPIO | Volume Up
UART TX | 19 | TXD | Low-power UART | External MCU_RX
UART RX | 20 | RXD | Low-power UART | External MCU_TX
3.3V | 1, 18 | VCC | Power | All modules VDD
GND | 6, 17 | GND | Ground | Common ground

## 3. Power Network (3.3V)

VCC (3.3V): E77 Pin1/Pin18 -> INMP441 VDD -> MAX98357A VDD -> 10uF capacitor GND: E77 Pin6/Pin17 -> INMP441 GND -> MAX98357A GND -> 100nF filter x3

## 4. I2S Audio Bus Connection

Signal | E77 Pin | INMP441 | MAX98357A
BCLK (Bit Clock) | PA5 (Pin30) | SCK | BCLK
LRCK (Word Select) | PB12 (Pin11) | WS | LRCK
DATA_IN (Mic) | PA12 (Pin14) | DATA (OUT) | -

DATA_OUT (Amp) | PA10 (Pin12) | - | DIN

## 5. Button Control (Using E77 On-board GPIO)

Button | E77 Pin | Function | Description
KEY1 (PTT) | PC13 (Pin7) | TX/RX Toggle | Press to TX, release to RX
KEY2 (Mode) | PB3 (Pin21) | Mode Switch | Click to switch, dbl-click to pair
KEY3 (Func) | PB5 (Pin23) | Channel Sel | Long press 3s for pairing
KEY4 (Vol+) | PB8 (Pin26) | Volume Ctrl | Click+, Dbl-click-

Button Circuit: Using STM32WLE5JC built-in 40K pull-up, no external resistor needed

## 6. Module Configuration

INMP441: L/R pin -> GND (Left channel address 0x48)
MAX98357A: GAIN -> GND (Default 9dB gain), SD -> 3.3V (Enable)

## 7. BOM (Bill of Materials)

Ref | Specification | Qty | Description
E77 | E77-400MBL-01 | 1 | LoRa wireless module
U1 | INMP441 module | 1 | Digital MEMS mic
U2 | MAX98357A module | 1 | I2S amplifier
C1, C5 | 10uF/10V tantalum | 2 | Power storage
C2-C4 | 100nF SMD capacitor | 3 | Decoupling
SPK | 8 Ohm / 1W speaker | 1 | Audio output
S1-S4 | Tact switch 6x6mm | 4 | Optional: PCB buttons

## 8. PCB Layout Guidelines

Routing Priority:
1. I2S signals (BCLK, LRCK, DATA) - Length mismatch < 5mil
2. Power traces - 3.3V (20mil), GND (30mil)
3. Button control lines - Standard (10mil)

Notes:
- Place mic near PCB edge
- Keep LoRa antenna away from audio signals
- Amplifier output away from sensitive signals

Intercom Schematic | E77-400MBL-01 + INMP441 + MAX98357A | v3.0

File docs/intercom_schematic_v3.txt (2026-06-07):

================================================================================
           实时对讲机原理图 (优化版) - 使用E77模块自带按键
================================================================================
                    E77-400MBL-01 + INMP441 + MAX98357A
================================================================================

                              3.3V
                                │
      ┌─────────────────────────┼─────────────────────────┐
      │                         │                         │
      │    ┌──────────────┐     │     ┌──────────────┐    │
      │    │E77-400MBL-01 │     │     │  INMP441     │    │
      │    │   LoRa模块   │     │     │ 数字麦克风    │    │
      │    ├──────────────┤     │     ├──────────────┤    │
      │  1─┼── 3.3V      ─┼─────┼─────┼── VDD        │    │
      │  2─┼── VCC       ─┼─────┼─────┼── 3.3V       │    │
      │  3─┼── REST      │     │     │              │    │
      │  4─┼── SWCLK     │     │     │  2─┬── GND    │    │
      │  5─┼── SWDIO     │     │     │    │    │      │    │
      │  6─┼── GND      ─┼─────┼─────┼────┴──────────│    │
      │  7─┼── PC13(WKUP2)     │     │              │    │
      │  8─┼── PA15      │     │     │  3─┬── L/R    │    │
      │  9─┼── PB0       │     │     │    │    │      │    │
      │ 10─┼── PB2       │     │     │    └── GND    │    │
      │ 11─┼── PB12(NSS)─┼─────┼─────┼── WS         │    │
      │ 12─┼── PA10(TX)  │     │     │              │    │
      │ 13─┼── PA11      │     │     │              │    │
      │ 14─┼── PA12(ETR)─┼─────┼─────┼── DATA       │    │
      │ 15─┼── PA9(CH2)  │     │     │              │    │
      │ 16─┼── PA8(MCO)  │     │     │              │    │
      │ 17─┼── GND      ─┼─────┼─────┼── GND        │    │
      │ 18─┼── 3.3V      │     │     │              │    │
      │ 19─┼── TXD (UART)    │     │  5─┬── SCK    │    │
      │ 20─┼── RXD (UART)    │     │    │    │      │    │
      │ 21─┼── PB3(IRQ0) │     │     │    └── I2S   │    │
      │ 22─┼── PB4       │     │     │              │    │
      │ 23─┼── PB5(IRQ1)─┼───────────┤              │    │
      │ 24─┼── PB6(ETR)  │     │     │              │    │
      │ 25─┼── PB7(RX)   │     │     │              │    │
      │ 26─┼── PB8(IRQ2)─┼───────────┘              │    │
      │ 27─┼── PA0       │       KEY_PTT            │    │
      │ 28─┼── PA1       │       │                  │    │
      │ 29─┼── PA4       │       │                  │    │
      │ 30─┼── PA5(SCK)  │       │                  │    │
      │    │              │       │                  │    │
      │    │   按键功能:  │       │                  │    │
      │    │   Pin7  - PC13  → KEY1 (PTT)           │    │
      │    │   Pin21 - PB3   → KEY2 (功能选择)      │    │
      │    │   Pin23 - PB5   → KEY3 (模式切换)      │    │
      │    │   Pin26 - PB8   → KEY4 (音量+)         │    │
      │    │              │       │                  │    │
      │    └──────────────┘       │                  │    │
      │                         │ │                  │    │
      │    ┌──────────────┐     │ │                  │    │
      │    │ MAX98357A    │     │ │                  │    │
      │    │  音频功放    │     │ │                  │    │
      │    ├──────────────┤     │ │                  │    │
      │    │              │     │ │                  │    │
      │  1─┼── VDD       ─┼─────┼─┼──────────────────┼────┼── 3.3V
      │  2─┼── GND       ─┼─────┼─┼──────────────────┼────┼── GND
      │  3─┼── DIN       ─┼─────┼─┴──────────────────┘     │
      │    │              │     │                          │
      │  4─┼── BCLK      ─┼─────┼──────┐                   │
      │  5─┼── LRCK      ─┼─────┼──────┤                   │
      │  6─┼── GAIN ──┬──┼─────┼──────┤                   │
      │    │         │  │     │      │                   │
      │    └── GND ──┘  │     │      │                   │
      │  7─┼── SD   ──┬──┼─────┼──────┘                   │
      │    │         │  │     │                            │
      │    └── 3.3V ──┘  │     │                            │
      │    └──────────────┘     │                            │
      │                         │                            │
      └─────────────────────────┘                            │
                                                              │
        ┌────────────────────────────────────────────────────┘
        │
        │    ┌─────────────────────────────────────────────┐
        │    │          物理按键布置 (可选扩展)             │
        │    │                                             │
        │    │   ┌────┐  ┌────┐  ┌────┐  ┌────┐           │
        │    │   │KEY1│  │KEY2│  │KEY3│  │KEY4│           │
        │    │   │PTT │  │模式│  │切换│  │音量│           │
        │    │   └────┘  └────┘  └────┘  └────┘           │
        │    │                                             │
        │    │   引脚映射:                                 │
        │    │   KEY1 → PC13 (Pin7)  - 内部上拉            │
        │    │   KEY2 → PB3  (Pin21) - 内部上拉            │
        │    │   KEY3 → PB5  (Pin23) - 内部上拉            │
        │    │   KEY4 → PB8  (Pin26) - 内部上拉            │
        │    └─────────────────────────────────────────────┘
        │
        └────────────────────────────────────────────────────

================================================================================
                        连线说明 (NET LIST)
================================================================================

【电源网络】
  VCC (3.3V):
    E77-400MBL-01 Pin1, Pin18
    INMP441 VDD
    MAX98357A VDD
    C1 (10uF) 储能电容

  GND:
    E77-400MBL-01 Pin6, Pin17
    INMP441 GND
    MAX98357A GND
    所有滤波电容地

【I2S音频总线】
  I2S_BCLK:
    E77 Pin30 (PA5) - SPI1_SCK
    MAX98357A BCLK
    INMP441 SCK

  I2S_LRCK:
    E77 Pin11 (PB12) - SPI2_NSS/I2S2_WS
    MAX98357A LRCK
    INMP441 WS

  I2S_DOUT (麦克风输入):
    E77 Pin14 (PA12) - TIM1_ETR
    INMP441 DATA

  I2S_DIN (功放输出):
    E77 Pin12 (PA10) - TIM1_CH3
    MAX98357A DIN

【UART串口 - 低功耗通信】
  UART_TX:
    E77 Pin19 (TXD)
    外部MCU_RX

  UART_RX:
    E77 Pin20 (RXD)
    外部MCU_TX

【按键控制 - 使用E77模块自带GPIO】
  KEY_PTT (主按键):
    E77 Pin7 (PC13) - WKUP2功能，可配置为GPIO输入
    内部上拉，无需外部电阻
    下降沿触发中断

  KEY_MODE (模式切换):
    E77 Pin21 (PB3) - RF_IRQ0，可配置为GPIO输入
    内部上拉
    下降沿触发

  KEY_FUNC (功能键):
    E77 Pin23 (PB5) - RF_IRQ1，可配置为GPIO输入
    内部上拉
    下降沿触发

  KEY_VOL+ (音量加):
    E77 Pin26 (PB8) - RF_IRQ2，可配置为GPIO输入
    内部上拉
    下降沿触发

【模块配置】
  INMP441 L/R: GND (左声道地址0x48)
  MAX98357A GAIN: GND (9dB默认增益)
  MAX98357A SD: 3.3V (使能输出)

================================================================================
                        E77模块可用按键引脚分析
================================================================================

【引脚复用为GPIO输入的候选引脚】

  引脚    名称      复用功能                    特点
  ─────────────────────────────────────────────────────────────
  Pin7    PC13      TAMP_IN1/RTC_TS/WKUP2      RTC唤醒，可作GPIO
  Pin8    PA15      JTDI                       调试口，可复用
  Pin21   PB3       RF_IRQ0                    外部中断推荐
  Pin22   PB4       NJTRST                     调试口，可复用
  Pin23   PB5       RF_IRQ1                    外部中断推荐
  Pin24   PB6       LPTIM1_ETR                 定时器捕获
  Pin25   PB7       LPTIM1_IN2/USART1_RX       UART接收/定时器
  Pin26   PB8       RF_IRQ2                    外部中断推荐
  Pin27   PA0       TIM2_CH1/TAMP_IN2/WKUP1    定时器/唤醒
  Pin28   PA1       TIM2_CH2                   定时器
  Pin29   PA4       SPI1_NSS                   SPI片选

【推荐按键引脚】

  ┌─────────────────────────────────────────────────────────────────────┐
  │  引脚      功能              中断类型        推荐用途               │
  ├─────────────────────────────────────────────────────────────────────┤
  │  PC13      唤醒/GPIO         下降沿          PTT主按键 (推荐)       │
  │  PB3       RF_IRQ0           下降沿          模式切换               │
  │  PB5       RF_IRQ1           下降沿          功能选择               │
  │  PB8       RF_IRQ2           下降沿          音量控制               │
  └─────────────────────────────────────────────────────────────────────┘

【内部上拉配置】

  STM32WLE5JC 内部上拉电阻约 40KΩ，对于按键电路足够使用。

  按键电路简化:
  ┌─────────┐
  │  按键    │
  │  ───    │  按下时接地
  │   │     │     │
  └──┼──────┼─────┘
     │     │
     └─┬───┘
       │
    内部上拉
       │
    (I/O引脚)

  软件配置:
  - GPIO模式: 输入浮空后使能内部上拉
  - 中断: 下降沿触发
  - 消抖: 软件消抖 (10-20ms)

================================================================================
                        按键功能定义
================================================================================

【默认按键功能】

  按键        E77引脚      功能说明
  ─────────────────────────────────────────────────────────────
  KEY1/PTT    PC13        发送/接收切换
                           - 按下: 发送模式 (麦克风采集)
                           - 松开: 接收模式 (LoRa播放)

  KEY2        PB3         模式切换
                           - 单击: 切换工作模式
                           - 双击: 配对功能

  KEY3        PB5         功能选择
                           - 切换频道
                           - 长按3秒: 进入配对模式

  KEY4        PB8         音量控制
                           - 单击: 音量+
                           - 双击: 音量-

【长按/短按检测】

  软件实现:
  - 短按: < 500ms
  - 长按: > 500ms
  - 超长按: > 3秒 (特殊功能)

  例程伪代码:
  void HAL_GPIO_EXTI_Callback(uint16_t GPIO_Pin) {
      uint32_t press_time = HAL_GetTick();
      
      while(HAL_GPIO_ReadPin(GPIO_Pin) == GPIO_PIN_RESET);
      uint32_t duration = HAL_GetTick() - press_time;
      
      if (duration < 500) {
          // 短按处理
      } else if (duration < 3000) {
          // 长按处理
      } else {
          // 超长按处理
      }
  }

================================================================================
                        PCB布局建议
================================================================================

┌────────────────────────────────────────────────────────────────────────────┐
│                           PCB布局图                                        │
├────────────────────────────────────────────────────────────────────────────┤
│                                                                            │
│   ┌────────────────────────────────────────────────────────────────────┐   │
│   │                           天线区域                                  │   │
│   │                     ═════════════════════                          │   │
│   │                     ║     E77模块        ║                          │   │
│   │                     ║   LoRa天线在此    ║                          │   │
│   │                     ╚════════════════════                          │   │
│   │                              │                                     │   │
│   │   ┌──────────────────────────┼──────────────────────────────────┐  │   │
│   │   │                          │                                  │  │   │
│   │   │   ┌─────────────┐       │        ┌─────────────┐           │  │   │
│   │   │   │             │  I2S  │        │             │           │  │   │
│   │   │   │   E77模块   │◄─────►│        │   INMP441   │           │  │   │
│   │   │   │             │       │        │    麦克风    │           │  │   │
│   │   │   │  按键引脚:  │       │        │             │           │  │   │
│   │   │   │  • PC13     │       │        └─────────────┘           │  │   │
│   │   │   │  • PB3      │       │                                     │  │   │
│   │   │   │  • PB5      │       │              ┌─────────────┐      │  │   │
│   │   │   │  • PB8      │       │              │             │      │  │   │
│   │   │   │             │       │              │  MAX98357A  │      │  │   │
│   │   │   └─────────────┘       │              │    功放     │      │  │   │
│   │   │                          │              │             │      │  │   │
│   │   │  按键布局:              │              └─────────────┘      │  │   │
│   │   │  ┌────┐ ┌────┐         │                                     │  │   │
│   │   │  │PTT │ │MODE│         │              ┌─────────────┐      │  │   │
│   │   │  └────┘ └────┘         │              │  扬声器     │      │  │   │
│   │   │                          │              │  8Ω/1W     │      │  │   │
│   │   └──────────────────────────┴──────────────┴─────────────┘      │  │   │
│   │                                                                    │  │   │
│   └────────────────────────────────────────────────────────────────────┘   │
│                                                                            │
│   ┌────────────────────────────────────────────────────────────────────┐   │
│   │                          电源区域                                   │   │
│   │   ┌────┐ ┌────┐ ┌────┐ ┌────┐ ┌────┐                             │   │
│   │   │ C1 │ │ C2 │ │ C3 │ │ C4 │ │ C5 │                             │   │
│   │   │10uF│ │100n│ │100n│ │100n│ │10uF│                             │   │
│   │   └────┘ └────┘ └────┘ └────┘ └────┘                             │   │
│   └────────────────────────────────────────────────────────────────────┘   │
│                                                                            │
│   走线优先级:                                                              │
│   1. I2S信号: BCLK, LRCK, DATA (长度差 < 5mil)                           │
│   2. 电源: 3.3V (20mil), GND (30mil)                                     │
│   3. 按键: 可用普通走线 (10mil)                                           │
│                                                                            │
└────────────────────────────────────────────────────────────────────────────┘

================================================================================
                        BOM物料清单 (精简版)
================================================================================

  位号          规格                数量    说明
  ─────────────────────────────────────────────────────────────
  E77           E77-400MBL-01       1      LoRa模块(含4个GPIO)
  U1            INMP441模块         1      数字麦克风
  U2            MAX98357A模块       1      I2S音频功放
  C1, C5        10uF/10V 钽电容     2      电源储能
  C2-C4         100nF 贴片电容      3      去耦电容
  SPK           8Ω 扬声器 (1W)      1      音频输出

  【可选】物理按键:
  S1            轻触开关 6x6mm      4      PCB安装按键 (TT/P模式/功能/音量)
  【可选】按键帽:
  红色帽        PTT按键帽          1      红色区分主按键
  黑色帽        功能按键帽         3      黑色普通按键

================================================================================
                        移除SW-PB后的优势
================================================================================

  ✅ 减少外部器件
     - 移除SW-PB按键模块
     - 移除1个10K电阻
     - 简化PCB布局

  ✅ 使用模块自带引脚
     - PC13 (Pin7): RTC唤醒引脚，可作GPIO
     - PB3 (Pin21): RF_IRQ0，中断功能
     - PB5 (Pin23): RF_IRQ1，中断功能
     - PB8 (Pin26): RF_IRQ2，中断功能

  ✅ 内部上拉
     - STM32WLE5JC内置40KΩ上拉
     - 无需外部上拉电阻
     - 软件配置即可使用

  ✅ 灵活性
     - 可选择使用模块测试点
     - 也可扩展PCB按键
     - 引脚功能可通过软件重映射

================================================================================

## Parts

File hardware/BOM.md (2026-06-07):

# 物料清单 v0.1

> 作者: vam-polf | 2026-06-07 | 来源: EasyEDA Pro 网表 | 全 53 项

## 核心模组/IC

| 位号 | 型号 | 封装 | 说明 | LCSC/供应商 |
|---|---|---|---|---|
| U1 | E77-400M22S | 模块 | 400MHz LoRa扩频无线模块 (STM32WLE5) | LCSC: C2777170 |
| U2 | WM8960CGEFL/RV | QFN-32 | 立体声音频编解码器 + 1W D类功放 | 停产, 需淘宝 |
| U3 | ME6211C33M5G-N | SOT-23-5 | 3.3V 500mA LDO 稳压器 | LCSC: C82942 |
| U4 | TP4056-42-ESOP8 | ESOP-8 | 1A 线性锂电池充电器 | LCSC: C382139 |
| U5 | DW01A | SOT-23-6 | 单节锂电池保护IC | LCSC: C351377 |
| U6 | 8205A | TSSOP-8 | 双N沟道 MOSFET 20V/6A | LCSC: C440346 |
| U8 | XL-1608SURC-06 | 0603 | 红色贴片LED | LCSC: C965802 |
| U9 | GL0603UG01 | 0603 | 翠绿高亮贴片LED | LCSC: C52372 |

## 连接器

| 位号 | 型号 | 封装 | 说明 |
|---|---|---|---|
| J1 | TYPE-C-31-M-12 | USB-C 母座 卧贴 | USB-C 充电/数据接口 |
| J2 | SMA-KE-5 | SMA 母座 正脚 | 天线接口 |
| J3 | 1.25T-2P卧贴 | PicoBlade 1.25mm 1x2P | 电池连接器 |
| J4 | 1271WV-2x3P | 2.54mm 2x3P 直插 | SWD 调试接口 |
| J5 | ZH1.5-2P-LT | ZH 1.5mm 1x2P 立贴 | 扬声器接口 |
| J6 | ZH1.5-2P-LT | ZH 1.5mm 1x2P 立贴 | 麦克风接口 |
| SW1 | TS-1187A-B-A-B | 5.1×5.1×1.5mm 立贴 | PTT 按键 |

## 电阻 (0603)

| 位号 | 阻值 | 精度 | 功率 | LCSC |
|---|---|---|---|---|
| R1 | 10kΩ | ±5% | 100mW | C25804 |
| R2 | 1kΩ | ±5% | 100mW | C16045 |
| R3 | 1kΩ | ±5% | 100mW | C16045 |
| R4 | 100Ω | ±5% | 100mW | C22779 |
| R5 | 1kΩ | ±5% | 100mW | C16045 |
| R6 | 10kΩ | ±5% | 100mW | C25804 |
| R7 | 0Ω | ±1% | 100mW | C26114 |
| R8 | 0Ω | ±1% | 100mW | C26114 |
| R9 | 0Ω | ±1% | 100mW | C26114 |
| R10 | 0Ω | ±1% | 100mW | C26114 |
| R11 | 0Ω | ±1% | 100mW | C26114 |
| R12 | 4.7kΩ | ±1% | 100mW | C23171 |
| R13 | 4.7kΩ | ±1% | 100mW | C23171 |
| R14 | 10kΩ | ±5% | 100mW | C25804 |
| R15 | 2.2kΩ | ±1% | 100mW | C22969 |
| R16 | 10kΩ | ±5% | 100mW | C25804 |
| R17 | 5.1kΩ | ±5% | 100mW | C23184 |
| R18 | 5.1kΩ | ±5% | 100mW | C23184 |
| R19 | 100kΩ | ±1% | 100mW | C25810 |
| R20 | 100kΩ | ±1% | 100mW | C25810 |

## 电容

| 位号 | 容值 | 耐压 | 封装 | LCSC |
|---|---|---|---|---|
| C1 | 22μF | 10V | 0805 | C45783 |
| C2 | 100nF | 50V | 0603 | C1525 |
| C3 | 100nF | 50V | 0603 | C1525 |
| C4 | 22μF | 10V | 0805 | C45783 |
| C5 | 10μF | 10V | 0805 | C15850 |
| C6 | 100nF | 50V | 0603 | C1525 |
| C7 | 22μF | 10V | 0805 | C45783 |
| C8 | 100nF | 50V | 0603 | C1525 |
| C9 | 100nF | 50V | 0603 | C1525 |
| C10 | 100nF | 50V | 0603 | C1525 |
| C11 | 10μF | 10V | 0805 | C15850 |
| C12 | 100nF | 50V | 0603 | C1525 |
| C13 | 100nF | 50V | 0603 | C1525 |
| C14 | 22μF | 10V | 0805 | C45783 |
| C15 | 100nF | 50V | 0603 | C1525 |
| C16 | 10μF | 10V | 0805 | C15850 |
| C17 | 10μF | 10V | 0805 | C15850 |
| C18 | 1μF | 50V | 0603 | C14663 |

## 汇总

| 类别 | 数量 |
|---|---|
| 模组/IC | 9 |
| 连接器/开关 | 8 |
| 电阻 (0603) | 20 |
| 电容 (0603/0805) | 18 |
| **总计** | **53** |

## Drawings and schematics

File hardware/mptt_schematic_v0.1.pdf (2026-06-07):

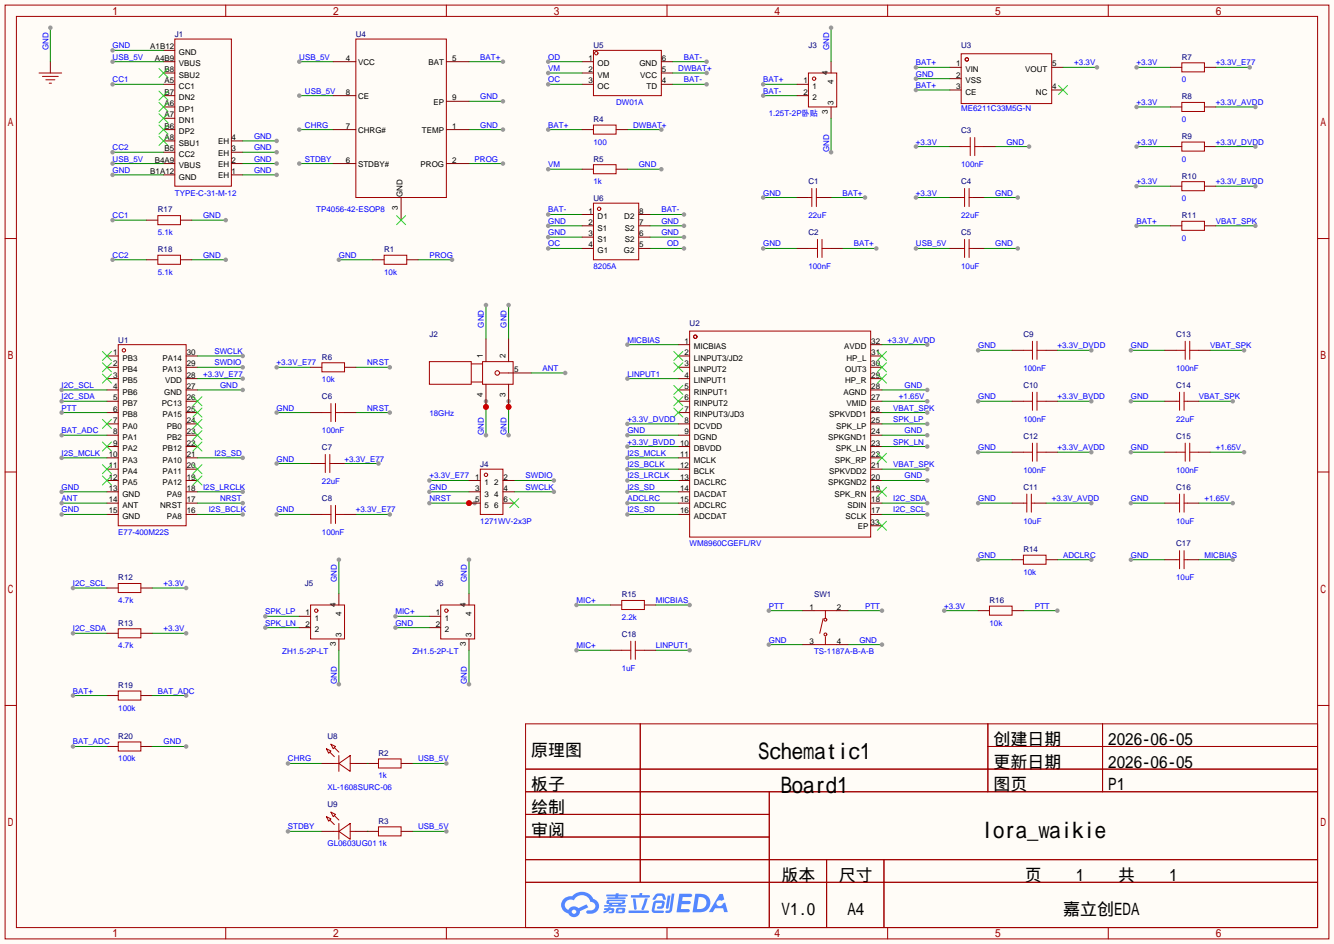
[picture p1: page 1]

原理图 | Schematic1 | 创建日期 | 2026-06-05

更新日期 | 2026-06-05

板子 | Board1 | 图页 | P1
绘制 | | lora_waikie
审阅

V1.0 | A4 | 嘉立创EDA

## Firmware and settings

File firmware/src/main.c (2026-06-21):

/*
 * MPTT Mode 1 — PTT 录音回放 (应用层)
 *
 * 本文件只负责"业务逻辑": 系统时钟bring-up、PTT 按键、录放状态机、
 * 数字后处理(去DC/高通/逐块AGC/噪声门/淡入淡出)、以及诊断(RESULT/DIAG)。
 *
 * 所有音频"底层"(MCLK/I2C/I2S/WM8960 寄存器、录放模式切换、逐样本读写)
 * 已封装到 audio_wm8960.c, 通过 audio_wm8960.h 接口调用 —— 默认不要改动底层。
 *
 * 诊断内存:
 *   RESULT (0x20000100): [0]=AA boot [1]=I2C err [2]=I2S(55) [3]=state
 *                        [4]=len_lo [5]=len_hi  [6]=idx     [7]=I2C_ISR
 *   DIAG   (0x20000110): [0]=录音错误计数 [7]=首次RXNE SR
 *                        [8]=dc [9]=vmin|vmax [10]=abs_mean [11]=buf_len
 *                        [13]=gain [14]=录音bmin|bmax / 播放UDR [15]=播放迭代
 *
 * Build: firmware\build.bat
 * Flash: pyocd flash -t stm32wle5cbux firmware\build\fw.bin
 * Test:  python firmware\tools\selftest.py
 */
#include <stdint.h>
#include "stm32wle5xx.h"
#include "audio_wm8960.h"

/* ─── SRAM 检查点 ─── */
#define RESULT  ((volatile uint8_t *)0x20000100)
#define DIAG    ((volatile uint32_t *)0x20000110)

/* ─── PTT 按键: PB8 (E77 pin 6), 上拉输入, 按下=低 ─── */
#define PTT_GPIO      GPIOB_BASE
#define PTT_PIN       8

/* ─── 录音缓冲: SRAM2 (0x20008000, 16KB), 单声道 int16 ─── */
#define AUDIO_BUF     ((int16_t *)0x20008000)
#define MAX_SAMPLES   8000   /* 8000/8929Hz ≈ 0.9s, 用满 SRAM2 */

/* ─── 状态机 ─── */
enum { ST_IDLE = 0, ST_RECORD = 1, ST_PLAYBACK = 2 };

/* ==================== PTT 按键 ==================== */
static void ptt_init(void) {
    GPIO_MODER(PTT_GPIO) &= ~(3U << (PTT_PIN * 2));   /* Input */
    GPIO_PUPDR(PTT_GPIO) &= ~(3U << (PTT_PIN * 2));
    GPIO_PUPDR(PTT_GPIO) |=  (1U << (PTT_PIN * 2));   /* Pull-up */
}

static inline int ptt_pressed(void) {
    return !(GPIO_IDR(PTT_GPIO) & (1U << PTT_PIN));
}

/* ==================== Main ==================== */
int main(void) {
    /* HSI16 → SYSCLK = 16MHz (系统级 bring-up) */
    RCC_CR |= RCC_CR_HSION;
    while (!(RCC_CR & RCC_CR_HSIRDY));
    RCC_CFGR = 0x00000001;
    while ((RCC_CFGR & 0x0C) != 0x04);
    RESULT[0] = 0xAA;

    /* 音频底层一次性初始化 (MCLK + I2S + I2C + WM8960, R19 设定一次永不改) */
    uint8_t err = audio_init();
    RESULT[1] = err ? 0xEE : 0x00;
    RESULT[7] = (uint8_t)(I2C1_ISR & 0xFF);
    RESULT[2] = (audio_dbg_i2scfgr() & I2SCFGR_I2SE) ? 0x55 : 0x00;

    ptt_init();
    RESULT[3] = ST_IDLE;

    uint8_t  state    = ST_IDLE;
    uint16_t buf_idx  = 0;
    uint16_t buf_len  = 0;
    uint8_t  rec_err  = 0;   /* audio_enter_record() 返回的 I2C 错误码 */

    while (1) {
        int pressed = ptt_pressed();

        switch (state) {

        /* ─── IDLE: 等 PTT 按下 ─── */
        case ST_IDLE:
            if (pressed) {
                rec_err = audio_enter_record();   /* WM8960→主, STM32→Slave RX, 含稳定延时 */
                DIAG[2] = audio_dbg_i2scfgr();
                buf_idx = 0;
                buf_len = 0;
                state = ST_RECORD;
                RESULT[3] = ST_RECORD;
            }
            break;

        /* ─── RECORD: PTT 按住 → 录音 ─── */
        case ST_RECORD:
            if (!pressed || buf_idx >= MAX_SAMPLES) {
                buf_len = buf_idx;

                /* 原始采集统计 → DIAG[8..12] (单声道连续, stride 1) */
                {
                    int32_t dc_sum = 0, lc = 0;
                    int16_t vmin = 32767, vmax = -32768;
                    for (uint16_t i = 0; i < buf_len; i++) {
                        int16_t v = AUDIO_BUF[i];
                        dc_sum += v; lc++;
                        if (v < vmin) vmin = v;
                        if (v > vmax) vmax = v;
                    }
                    int32_t dc = (lc > 0) ? (dc_sum / lc) : 0;
                    int32_t abs_sum = 0;
                    for (uint16_t i = 0; i < buf_len; i++) {
                        int16_t v = AUDIO_BUF[i] - (int16_t)dc;
                        abs_sum += (v > 0) ? v : -v;
                    }
                    int32_t abs_mean = (lc > 0) ? (abs_sum / lc) : 0;
                    DIAG[8]  = (uint32_t)(uint16_t)dc;
                    DIAG[9]  = (uint32_t)((uint16_t)vmin | ((uint16_t)vmax << 16));
                    DIAG[10] = (uint32_t)abs_mean;
                    DIAG[11] = (uint32_t)buf_len;
                    DIAG[12] = (uint32_t)(lc);
                }

                /* 后处理(单声道): 去DC → 二阶高通(滤工频) → 逐块AGC + 噪声门 → 淡入淡出 */
                if (buf_len > 200) {
                    int32_t dc_sum = 0;
                    for (uint16_t i = 0; i < buf_len; i++) dc_sum += AUDIO_BUF[i];
                    int32_t dc = dc_sum / buf_len;
                    /* 去DC + 二阶高通(截止≈250Hz): 滤掉 50Hz 工频嗡声及谐波 */
                    int32_t lp1 = 0, lp2 = 0;
                    for (uint16_t i = 0; i < buf_len; i++) {
                        int32_t x = (int32_t)AUDIO_BUF[i] - dc;
                        lp1 += ((x - lp1) * 45) >> 8; int32_t h1 = x - lp1;   /* 1级HPF */
                        lp2 += ((h1 - lp2) * 45) >> 8; int32_t h2 = h1 - lp2; /* 2级HPF */
                        AUDIO_BUF[i] = (int16_t)h2;
                    }

                    /* 分块统计: 每 BLK 个样本(≈16ms)算绝对均值 */
                    #define BLK 128
                    #define MAXBLK 80
                    uint16_t nblk = buf_len / BLK;
                    if (nblk > MAXBLK) nblk = MAXBLK;
                    int32_t blev[MAXBLK];
                    int32_t bgain[MAXBLK];   /* 逐块增益, ×16 定点 */
                    int32_t bmin = 0x7FFFFFFF, bmax = 0;
                    for (uint16_t b = 0; b < nblk; b++) {
                        int32_t s = 0;
                        for (uint16_t k = 0; k < BLK; k++) {
                            int16_t v = AUDIO_BUF[b * BLK + k];
                            s += (v < 0) ? -v : v;
                        }
                        blev[b] = s / BLK;
                        if (blev[b] < bmin) bmin = blev[b];
                        if (blev[b] > bmax) bmax = blev[b];
                    }
                    int32_t thr = bmin + (bmax - bmin) / 8;   /* 噪声门限 */
                    DIAG[14] = (uint32_t)((uint16_t)bmin | ((uint16_t)bmax << 16));
                    uint8_t has_speech = (bmax > bmin * 3) && (bmax > 35);

                    /* 逐块AGC: 语音块→拉到 TARGET(响且均匀); 噪声块→增益0(静音) */
                    const int32_t TARGET = 14000;
                    for (uint16_t b = 0; b < nblk; b++) {
                        if (!has_speech || blev[b] < thr) {
                            bgain[b] = 0;
                        } else {
                            int32_t g = TARGET * 16 / blev[b];
                            if (g < 16)      g = 16;
                            if (g > 32 * 16) g = 32 * 16;
                            bgain[b] = g;
                        }
                    }
                    /* 平滑增益包络: attack 快、release 慢, 防抽吸/顿挫 */
                    {
                        int32_t g = 0;
                        for (uint16_t b = 0; b < nblk; b++) {
                            int32_t t = bgain[b];
                            if (t > g) g += (t - g) >> 1;
                            else       g += (t - g) >> 3;
                            bgain[b] = g;
                        }
                    }
                    /* 应用: 块间增益逐样本线性插值, 硬限幅 */
                    for (uint16_t b = 0; b < nblk; b++) {
                        uint16_t base = b * BLK;
                        int32_t g0 = bgain[b];
                        int32_t g1 = (b + 1 < nblk) ? bgain[b + 1] : bgain[b];
                        for (uint16_t k = 0; k < BLK; k++) {
                            int32_t gc = g0 + ((g1 - g0) * (int32_t)k) / BLK;
                            int32_t v = ((int32_t)AUDIO_BUF[base + k] * gc) >> 4;
                            if (v >  31000) v =  31000;
                            if (v < -31000) v = -31000;
                            AUDIO_BUF[base + k] = (int16_t)v;
                        }
                    }
                    DIAG[13] = (uint32_t)(bgain[nblk / 2] >> 4);
                    /* 尾部不足一块的样本: 当静音 */
                    for (uint16_t i = nblk * BLK; i < buf_len; i++) AUDIO_BUF[i] = 0;

                    /* 首尾淡入淡出, 消播放起止"咔哒" */
                    uint16_t fade = 256;
                    if (fade > buf_len / 4) fade = buf_len / 4;
                    for (uint16_t k = 0; k < fade; k++) {
                        AUDIO_BUF[k] =
                            (int16_t)((int32_t)AUDIO_BUF[k] * k / fade);
                        uint16_t j = buf_len - 1 - k;
                        AUDIO_BUF[j] =
                            (int16_t)((int32_t)AUDIO_BUF[j] * k / fade);
                    }
                }

                /* 记录录音期诊断, 然后切到播放 */
                DIAG[0] = (uint32_t)rec_err + audio_rx_error_frames();
                DIAG[7] = audio_rx_first_sr();

                uint8_t e = audio_enter_playback();   /* STM32→Master TX, WM8960→从 */
                DIAG[1] = e;
                DIAG[5] = audio_dbg_i2scfgr();
                buf_idx = 0;
                DIAG[14] = 0;   /* 播放 UDR 计数清零(覆盖录音期 bmin/bmax) */
                DIAG[15] = 0;   /* 播放迭代计数清零 */
                RESULT[3] = ST_PLAYBACK;
                RESULT[4] = (uint8_t)(buf_len);
                RESULT[5] = (uint8_t)(buf_len >> 8);
                state = ST_PLAYBACK;
            } else {
                int16_t s;
                if (audio_read_sample(&s)) {
                    AUDIO_BUF[buf_idx++] = s;
                }
            }
            break;

        /* ─── PLAYBACK: 单声道 → 同一样本发左右两次(驱动内部处理) ─── */
        case ST_PLAYBACK:
            if (buf_idx >= buf_len) {
                RESULT[3] = ST_IDLE; state = ST_IDLE;
            } else {
                DIAG[15]++;
                DIAG[14] = audio_tx_underruns();
                if (audio_write_sample(AUDIO_BUF[buf_idx])) buf_idx++;
            }
            break;
        }

        RESULT[6] = (uint8_t)(buf_idx);
    }
}

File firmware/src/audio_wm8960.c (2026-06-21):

/*
 * audio_wm8960.c — MPTT 音频底层驱动实现 (STM32WLE5 + WM8960)
 *
 * ███ 本文件是"已实测调通的底层", 默认冻结。修改前务必先读: ███
 *     D:/kb/wm8960/mptt-从零调试实战手册.md
 *
 * 半双工要点:
 *   播放: STM32 Master TX + WM8960 Slave  (已验证, 同 test_tone)
 *   录音: WM8960 Master + STM32 Slave RX   (已验证, 同 rx_test)
 *   R19(PWR1)=0x1FE 在 init 设定一次, 永不改变 → ADC/MICB/VMID 始终上电, 无启动瞬态。
 *
 * STM32WL I2S 三大铁律:
 *   1. SPI2S2SEL=10(SYSCLK)   2. SPE=1(即使 I2SMOD=1)   3. MCKOE=0(PA3 用 TIM2/AF1)
 *
 * WM8960 共线: ADCDAT(pin16)+DACDAT(pin14) 短接到 I2S_SD(PA10)
 *   录音: WM8960 Master, R18 TRIS=0(ADCDAT 驱动), LRCM=1
 *   播放: WM8960 Slave,  R18 TRIS=1(ADCDAT 三态), STM32 驱动 DACDAT
 */
#include "audio_wm8960.h"
#include "stm32wle5xx.h"

/* ==================== 私有状态 ==================== */
static uint8_t  s_rx_lr;        /* 录音帧内声道: 0=左(存) 1=右(丢) */
static uint16_t s_rx_discard;   /* 录音上电预热丢弃计数 */
static uint8_t  s_tx_lr;        /* 播放: 0=待发左 1=待发右(同一单声道发两次) */
static uint32_t s_rx_err;       /* 录音期 I2S 错误帧累计 */
static uint32_t s_rx_first_sr;  /* 录音首个 RXNE 时 SR 快照(0=未发生) */
static uint32_t s_tx_udr;       /* 播放期 UDR 欠载累计 */

/* ==================== 私有工具 ==================== */
static void delay(volatile uint32_t n) {
    while (n--) __asm__ volatile("nop");
}

/* ==================== I2C1 ==================== */
static void i2c1_init(void) {
    RCC_APB1ENR1 &= ~RCC_APB1ENR1_I2C1EN;
    delay(1000);
    RCC_APB1ENR1 |= RCC_APB1ENR1_I2C1EN;
    delay(100);
    I2C1_CR1 = 0;

    /* Bus recovery: SCL toggle 9x */
    GPIO_MODER(GPIOB_BASE) = (GPIO_MODER(GPIOB_BASE) & ~(3U<<12)) | (1U<<12);
    GPIO_OTYPER(GPIOB_BASE) &= ~(1U<<6);
    GPIO_PUPDR(GPIOB_BASE) &= ~(3U<<12);
    for (int i = 0; i < 9; i++) {
        GPIO_BSRR(GPIOB_BASE) = (1U << 22);
        delay(100);
        GPIO_BSRR(GPIOB_BASE) = (1U << 6);
        delay(100);
    }

    GPIO_MODER(GPIOB_BASE) &= ~((3U<<12)|(3U<<14));
    GPIO_MODER(GPIOB_BASE) |=  ((2U<<12)|(2U<<14));
    GPIO_OTYPER(GPIOB_BASE) |= (1U<<6)|(1U<<7);
    GPIO_PUPDR(GPIOB_BASE) &= ~((3U<<12)|(3U<<14));
    GPIO_PUPDR(GPIOB_BASE) |=  ((1U<<12)|(1U<<14));
    GPIO_AFRL(GPIOB_BASE) &= ~((0xFU<<24)|(0xFU<<28));
    GPIO_AFRL(GPIOB_BASE) |=  ((4U<<24)|(4U<<28));
    I2C1_CR1 = 0;
    I2C1_TIMINGR = 0x00503D5B;
    I2C1_CR1 = 1;
}

/* WM8960 I2C 写: 返回 0=成功, 1/2/3=超时, 4=NACK */
static uint8_t wm_write(uint8_t reg, uint16_t val) {
    uint8_t b1 = (reg << 1) | ((val >> 8) & 1);
    uint8_t b2 = val & 0xFF;
    I2C1_ICR = 0x3F38;
    I2C1_CR2 = (0x1A << 1) | (2U << 16) | (1U << 25) | (1U << 13);
    uint32_t t = 100000;
    while (!(I2C1_ISR & I2C_ISR_TXIS) && --t); if (!t) return 1;
    I2C1_TXDR = b1;
    t = 100000;
    while (!(I2C1_ISR & I2C_ISR_TXIS) && --t); if (!t) return 2;
    I2C1_TXDR = b2;
    t = 100000;
    while (!(I2C1_ISR & I2C_ISR_STOPF) && --t); if (!t) return 3;
    I2C1_ICR = I2C_ISR_STOPF;
    if (I2C1_ISR & I2C_ISR_NACKF) return 4;
    return 0;
}

/* ==================== TIM2 MCLK (PA3, 2.286MHz) ==================== */
static void mclk_init(void) {
    RCC_APB1ENR1 |= RCC_APB1ENR1_TIM2EN;
    delay(100);
    GPIO_AFRL(GPIOA_BASE) &= ~(0xFU<<12);
    GPIO_AFRL(GPIOA_BASE) |=  (1U<<12);   /* PA3 = AF1 (TIM2_CH4) */
    GPIO_MODER(GPIOA_BASE) &= ~(3U<<6);
    GPIO_MODER(GPIOA_BASE) |=  (2U<<6);
    GPIO_OSPEEDR(GPIOA_BASE) |= (3U<<6);
    TIM2_ARR = 6;       /* Period=7 → MCLK=16MHz/7=2.286MHz */
    TIM2_CCR4 = 3;      /* 占空比 43% */
    TIM2_CCMR2 = (6U << 12) | (1U << 11);
    TIM2_CCER = (1U << 12);
    TIM2_CR1 = 1;
}

/* ==================== I2S2 Master TX (播放态打底) ==================== */
static void i2s2_master_tx_init(void) {
    RCC_APB1ENR1 |= RCC_APB1ENR1_SPI2EN;
    delay(100);

    /* GPIO AF: PA3=AF1(TIM2), PA8=AF5(SPI2_CK), PA9=AF3(SPI2_WS), PA10=AF5(SPI2_SD) */
    GPIO_AFRL(GPIOA_BASE) &= ~(0xFU<<12);
    GPIO_AFRL(GPIOA_BASE) |=  (1U<<12);
    GPIO_AFRH(GPIOA_BASE) &= ~((0xFU<<0)|(0xFU<<4)|(0xFU<<8));
    GPIO_AFRH(GPIOA_BASE) |=  ((5U<<0)|(3U<<4)|(5U<<8));

    uint32_t tmp = GPIO_MODER(GPIOA_BASE);
    tmp &= ~((3U<<6)|(3U<<16)|(3U<<18)|(3U<<20));
    tmp |=  ((2U<<6)|(2U<<16)|(2U<<18)|(2U<<20));
    GPIO_MODER(GPIOA_BASE) = tmp;
    GPIO_OSPEEDR(GPIOA_BASE) |= ((3U<<6)|(3U<<16)|(3U<<18)|(3U<<20));

    /* TIM2 已在 mclk_init 中启动 */

    /* I2S2 Master TX: I2SPR ODD=0, DIV=14 (P=28) + CHLEN=1(32位帧)
     *   → Fs = 16M/(64×28) = 8929Hz = MCLK/256, DAC 时钟同步(关键, 否则回放杂音) */
    SPI2_I2SCFGR = 0;
    SPI2_CR1 = 0;
    SPI2_CR2 = 0;
    SPI2_I2SPR = (0U << 9) | (0U << 8) | 14;  /* ODD=0, DIV=14 → Fs=8929Hz=MCLK/256 */
    SPI2_I2SCFGR = I2SCFGR_I2SMOD | (2U << I2SCFGR_I2SCFG_SHIFT) | I2SCFGR_CHLEN;  /* Master TX, CHLEN=1 */
    SPI2_CR1 = (1U << 6);  /* SPE=1 */
    SPI2_I2SCFGR |= I2SCFGR_I2SE;

    GPIO_MODER(GPIOA_BASE) = (GPIO_MODER(GPIOA_BASE) & ~((3U<<18)|(3U<<20)))
                           | (2U<<18) | (2U<<20);
    __asm__ volatile("dsb");
}

/* 完全复位 SPI2 外设(关时钟→开时钟), 清除多次切换后的内部残留状态 */
static void i2s2_clear_flags(void) {
    RCC_APB1ENR1 &= ~RCC_APB1ENR1_SPI2EN;
    for (volatile int i = 0; i < 100; i++) __asm__ volatile("nop");
    RCC_APB1ENR1 |= RCC_APB1ENR1_SPI2EN;
    for (volatile int i = 0; i < 100; i++) __asm__ volatile("nop");
}

/* TX→RX: STM32 Slave RX (WM8960 Master)
 * CHLEN=0(16bit)+BCLKDIV=/8 → 32 SCLK/LRCLK 匹配 WM8960 WL=00; CKPOL=1 下降沿采样 */
static void i2s_switch_to_rx(void) {
    SPI2_I2SCFGR &= ~I2SCFGR_I2SE;
    for (volatile int i = 0; i < 500; i++) __asm__ volatile("nop");
    i2s2_clear_flags();
    SPI2_I2SCFGR = 0; SPI2_CR1 = 0; SPI2_CR2 = 0;
    SPI2_I2SPR = 0;
    SPI2_I2SCFGR = I2SCFGR_I2SMOD
                 | (1U << I2SCFGR_I2SCFG_SHIFT)   /* Slave RX */
                 | (1U << 3)                      /* CKPOL=1: 下降沿采样 */
                 | (1U << 12);                    /* ASTRTEN=1: 电平检测, 非边沿 */
    SPI2_CR1 = (1U << 6);
    SPI2_I2SCFGR |= I2SCFGR_I2SE;
    GPIO_MODER(GPIOA_BASE) = (GPIO_MODER(GPIOA_BASE) & ~((3U<<16)|(3U<<18)|(3U<<20)))
                           | (2U<<16) | (2U<<18) | (2U<<20);
    __asm__ volatile("dsb"); __asm__ volatile("isb");
}

/* RX→TX: STM32 Master TX (WM8960 Slave) */
static void i2s_switch_to_tx(void) {
    SPI2_I2SCFGR &= ~I2SCFGR_I2SE;
    for (volatile int i = 0; i < 500; i++) __asm__ volatile("nop");
    i2s2_clear_flags();   /* 清除上一轮 RX 的状态标志 */

    SPI2_I2SCFGR = 0;
    SPI2_CR1 = 0;
    SPI2_CR2 = 0;
    SPI2_I2SPR = (0U << 9) | (0U << 8) | 14;  /* ODD=0, DIV=14 → Fs=8929Hz=MCLK/256 */
    SPI2_I2SCFGR = I2SCFGR_I2SMOD
                 | (2U << I2SCFGR_I2SCFG_SHIFT)    /* Master TX */
                 | I2SCFGR_CHLEN;                  /* CHLEN=1 */
    SPI2_CR1 = (1U << 6);
    SPI2_I2SCFGR |= I2SCFGR_I2SE;

    GPIO_PUPDR(GPIOA_BASE) &= ~(3U << 20);
    GPIO_MODER(GPIOA_BASE) = (GPIO_MODER(GPIOA_BASE) & ~((3U<<18)|(3U<<20)))
                           | (2U<<18) | (2U<<20);
    __asm__ volatile("dsb");
}
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

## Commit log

2026-01-24 更新方案A硬件连接说明
2026-06-07 feat: LoRa Walkie Talkie v2.5 完整设计
    - 上传 EasyEDA Pro 工程文件 (lora_waikie20260605.eprj2)
    - 新增完整物料清单 BOM.md (53项, 含LCSC编号)
    - 新增原理图设计说明 SCHEMATIC.md (6大功能模块)
    - 新增PCB设计说明 PCB.md (2层FR-4 35x55mm)
    - 新增网络连接表 NETLIST.md (40个网络)
    - 更新项目README (架构图+规格参数)
2026-06-07 reorganize: clean project structure
    - docs/: intercom analysis, schematics
    - reference/datasheets/: E77, STM32WLE5, INMP441
    - archive/v1.0/: initial lora_waikie.eprj2
    - assets/: project zips, images
    - root: latest design docs + .eprj2
    [E77-400MBL-01-PIN.xlsx, STM32WLE5.xlsx, intercom_schematic.kicad_sch]
2026-06-07 reorganize: proper project structure
    hardware/ - current v2.5 design (eprj2 + docs)
    docs/ - design analysis
    reference/ - chip datasheets
    archive/ - v1.0 + v2.0_kicad history + old zips
    tools/ - helper scripts
    cleanup: removed 4 duplicate/obsolete files
    [E77-400MBL-01-PIN.xlsx, intercom_schematic.kicad_sch]
2026-06-07 docs: add comprehensive v2.5 design document
    - new: docs/DESIGN_v2.5.md (18KB, 10 chapters)
    - system overview, architecture, pin mappings
    - E77 + WM8960 detailed analysis
    - power tree with TP4056/DW01A/ME6211
    - BOM, PCB guidelines, design rationale
    - cleanup: remove outdated intercom/kicad artifacts
    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
    [intercom_schematic.kicad_sch]
2026-06-07 docs: rename to v0.1, add schematic PDF export
    - DESIGN_v2.5.md → DESIGN_v0.1.md (version corrected)
    - hardware/: add mptt_schematic_v0.1.pdf (292KB)
2026-06-07 review: systematic correction of all docs
    - MPTT = Mini Push To Talk (not Multi-Purpose Talkie Terminal)
    - author: ShiTingShui → vam-polf
    - version: all unified to v0.1
    - README: complete rewrite with correct structure
    - SCHEMATIC: 55→53 components, 磁珠→0Ω跳线
    - PCB: 52 SMD + 1 THT (J4), not all SMD
    - NETLIST: CC1 pull-down added
    - DESIGN_v0.1: author and version corrected
    - BOM: unified header format
2026-06-19 添加固件源代码和文档，更新.gitignore排除编译产物
2026-06-19 移除 firmware_test 目录，添加到 .gitignore
2026-06-19 修复 .gitignore 格式
2026-06-21 Refactor firmware into audio driver layer and clean up project docs.
    Extract WM8960/I2S recording-playback into audio_wm8960 driver, reorganize firmware as src/include/tools, remove obsolete test utilities and outdated docs, and align hardware netlist with verified br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
